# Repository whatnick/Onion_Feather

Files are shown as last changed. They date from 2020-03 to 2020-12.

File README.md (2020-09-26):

View this project on [CADLAB.io](https://cadlab.io/project/23183). 

# Onion-Omega 2 - Feather Adapter
Adapter board adding much needed USB , Lipo , ADC's etc to Onion-Omega form factor and converting it to an Adafruit Feather

## Renders

**Top Render**
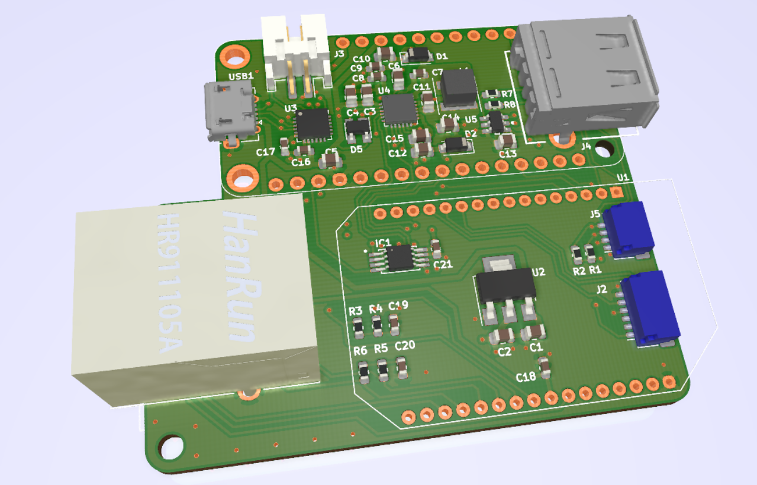
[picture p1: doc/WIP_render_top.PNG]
top render


**Bottom Render**
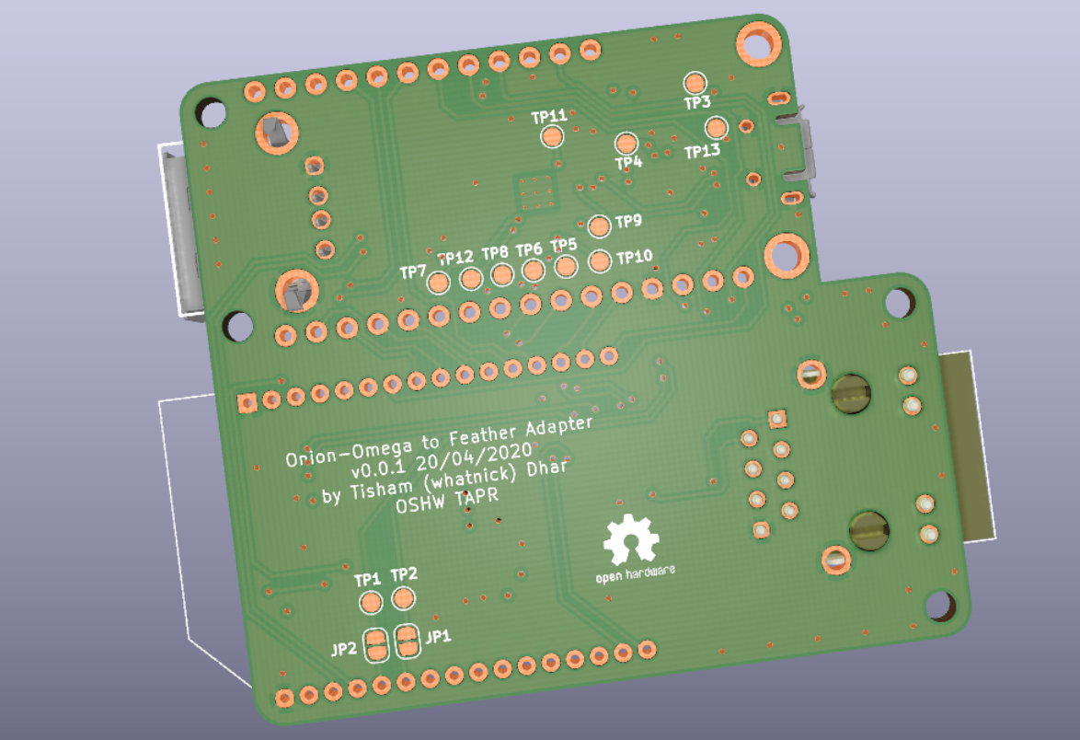
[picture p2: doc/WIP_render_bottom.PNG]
bottom render


## Roadmap Features
- USB-Serial adapter on-board for direct access to Onion Serial port - [CP2102](https://au.mouser.com/ProductDetail/Silicon-Labs/CP2102N-A02-GQFN20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)
- [3.3v](http://www.ti.com/product/TPS63001) and [5v](http://www.ti.com/product/TPS63002) power rails with buck-boost converters and power-path IC's
- USB host to expose the Onion USB pins and add USB devices
- Power OR from VUSB and VBAT using Dual Common Cathode Schottky - [PMEG4010CPA,115](https://au.mouser.com/ProductDetail/Nexperia/PMEG4010CPA115?qs=O%2F7ihdSJpea%252BrtmRoPSGEg%3D%3D)
- Ethernet jack with built-in or external pulse transformer - [Amphenol](https://au.mouser.com/ProductDetail/Amphenol-Commercial-Products/RJMG1BD3B8K1ANR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) or [Hanrun](https://www.snapeda.com/parts/HR911105A/DFRobot/view-part/?ref=search&t=HR911105A)
- Battery charger and buck-boost converter - [BQ25895](http://www.ti.com/product/BQ25895)
- 8-channel I2C ADC for the ADC pins - [AD7997](https://www.analog.com/en/products/ad7997.html#product-overview)
- 2-channel I2C ADC for the ADC pins - [MAX11646EUA+](https://au.mouser.com/new/maxim-integrated/maxim-max11646-max11647/) with other Analog pins services by [Onion PCM/PWM](https://docs.onion.io/omega2-docs/generating-pwm-signals.html) pins.
- Dense 20 pin 1.0 mm pitch board-to-wire connector for all pins - [Molex 203566-2007](https://au.mouser.com/ProductDetail/Molex/203566-2007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)
- Qwiic format JST-SH I2C bus connector - [Qwiic](https://www.sparkfun.com/qwiic)
- USB-host protection using [STF202](https://www.onsemi.com/pub/Collateral/STF202-22T1-D.PDF)
- SPI Bus isolation using [74HC367](https://www.ti.com/lit/ds/symlink/sn74hc367.pdf?ts=1601076323582) hex non-inverting tri-state buffer. This can also be used for I2C bus isolation and driving in later revisions using the left over x2 tristate buffers.

## Reference Prior Art
- [Adafruit ESP32 Huzzah Feather](https://github.com/adafruit/Adafruit-HUZZAH32-ESP32-Feather-PCB)
- [BQ25895 Breakout](https://www.bernebeer.nl/new-bq25895-breakout/)
- [Qwiic Featherwing](https://github.com/hongselectronics/Qwiic_Featherwing)

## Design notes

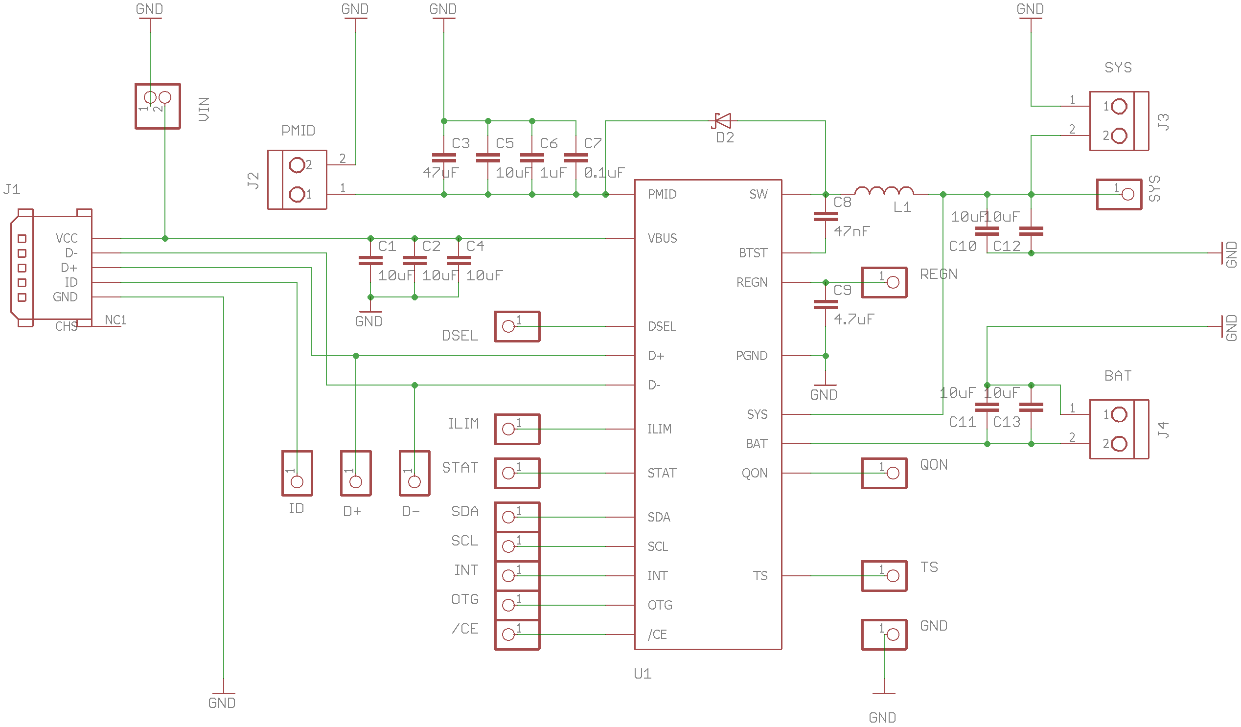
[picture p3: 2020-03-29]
doc/BQ25895-breakout-v2-schematic.png

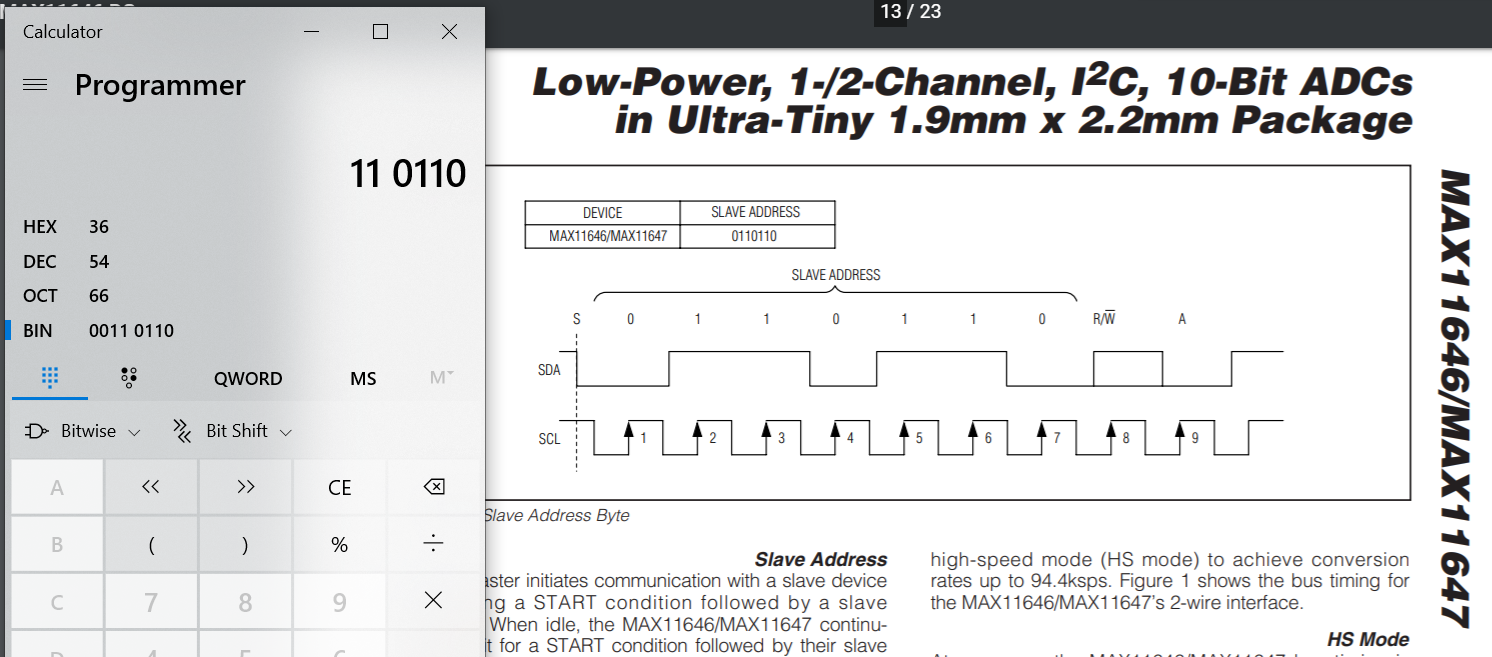
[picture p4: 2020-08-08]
doc/MAX11646_i2c.PNG

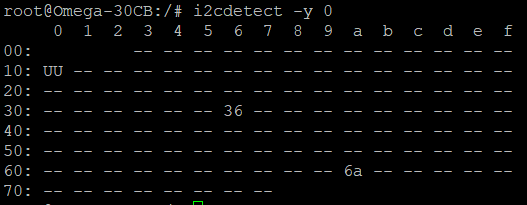
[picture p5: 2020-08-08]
doc/omega_i2c_scan.PNG

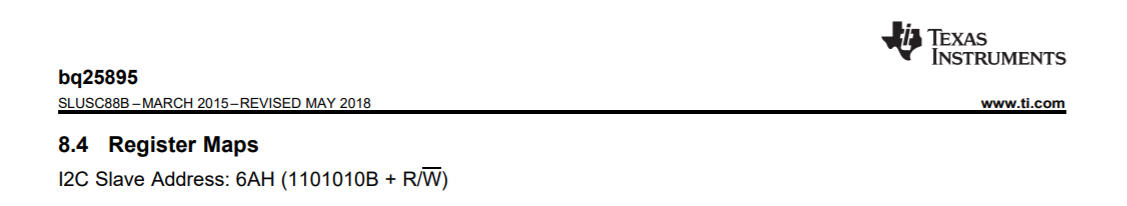
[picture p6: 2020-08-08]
doc/BQ25895_i2c.PNG

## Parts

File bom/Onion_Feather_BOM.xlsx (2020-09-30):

References | manf# | Value | Footprint | Quantity
C6 | 0805YD475MAT2A | 4.7u | C_0805_2012Metric | 1
C8, C17, C19, C20, C21 | C0603C104M4RAC | 100n | C_0603_1608Metric | 5
C9, C16, C18 | C0603C105M4PAC7411 | 1u | C_0603_1608Metric | 3
C7 | C0603C473M4RACTU | 47n | C_0603_1608Metric | 1
C1, C2, C3, C4, C5, C10, C11, C12, C14, C15 | C0805C106K4PAC | 10u | C_0805_2012Metric | 10
C13 | C0805C476M9PACTU | 47u | C_0805_2012Metric | 1
R9, R10, R11 | CRCW060310K0JNEBC | 10K | R_0603_1608Metric | 3
R7, R8 | MCT0603MZ0000ZP500 | 0R | R_0603_1608Metric | 2
R1, R2 | RT0603DRE074K7L | 4.7K | R_0603_1608Metric | 2
R3, R4, R5, R6 | RT0603FRD0749R9L | 49.9R | R_0603_1608Metric | 4
L1 | XAL5030-222MEC | 2.2u | L_Coilcraft_XAL5030 | 1
D1 | MBR130T3G | D_Schottky | D_SOD-123 | 1
D2 | PMEG4010CPA,115 | D_Schottky_x2_KCom_AAK | SOT1061 | 1
D5 | SP0503BAHTG | SP0503BAHT | SOT-143 | 1
U4 | BQ25895RTW | BQ25895RTW | Texas_S-PWQFN-N24_EP2.7x2.7mm_ThermalVias | 1
U3 | CP2102N-A01-GQFN24R | CP2102N-A01-GQFN24 | QFN-24-1EP_4x4mm_P0.5mm_EP2.6x2.6mm | 1
U5 | STF202-22T1G | STF202-22T1G | SOT95P275X110-6N | 1
U2 | TLV1117-33IDCYR | AP1117-33 | SOT-223-3_TabPin2 | 1
USB1 | 47590-0001 | USB_B_Micro | USB_Micro-AB_Molex_47590-0001 | 1
IC1 | MAX11646EUA+T | MAX11646EUA+T | TSSOP-8_4.4x3mm_P0.65mm | 1
IC2 | SN74HC367PWR | SN74HC367PWR | SOP65P640X120-16N | 1
J4 | 67643-0910 | USB_A | 67643-0910 | 1
J1 | HR911105A | HR911105A | HANRUN_HR911105A | 1
J3 | S2B-PH-SM4-TB(LF)(SN) | Conn_01x02 | JST_PH_S2B-PH-SM4-TB_1x02-1MP_P2.00mm_Horizontal | 1
J5 | SM04B-SRSS-TB(LF)(SN) | M04PTH | JST_SH_SM04B-SRSS-TB_1x04-1MP_P1.00mm_Horizontal | 1
J2 | SM06B-SRSS-TB(LF)(SN) | CON_HEADER_PRG_AVR_ICSP-PTH | JST_SH_SM06B-SRSS-TB_1x06-1MP_P1.00mm_Horizontal | 1

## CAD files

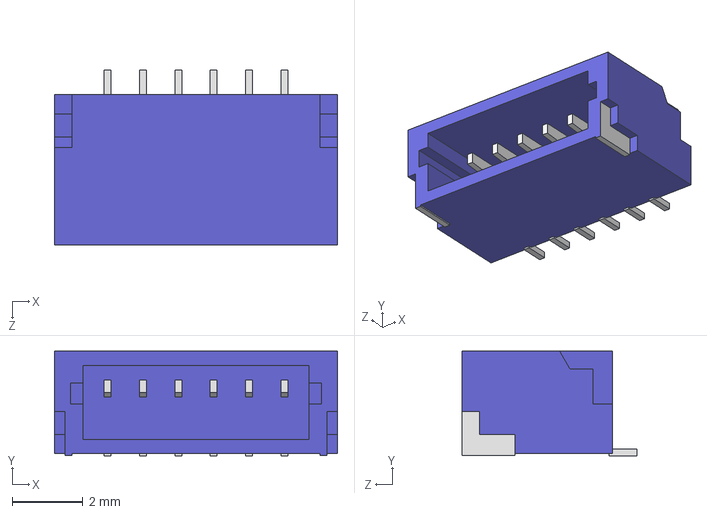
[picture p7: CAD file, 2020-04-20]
3dmodels/SM06B-SRSS-TB.STEP
8.00 x 2.96 x 4.95 mm

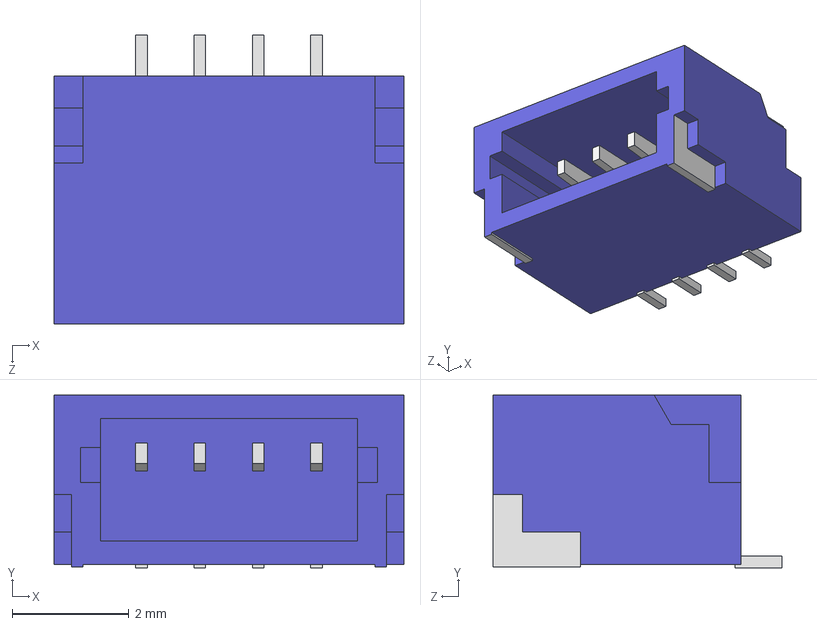
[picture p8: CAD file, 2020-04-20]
3dmodels/SM04B-SRSS-TB.STEP
6.00 x 2.96 x 4.95 mm

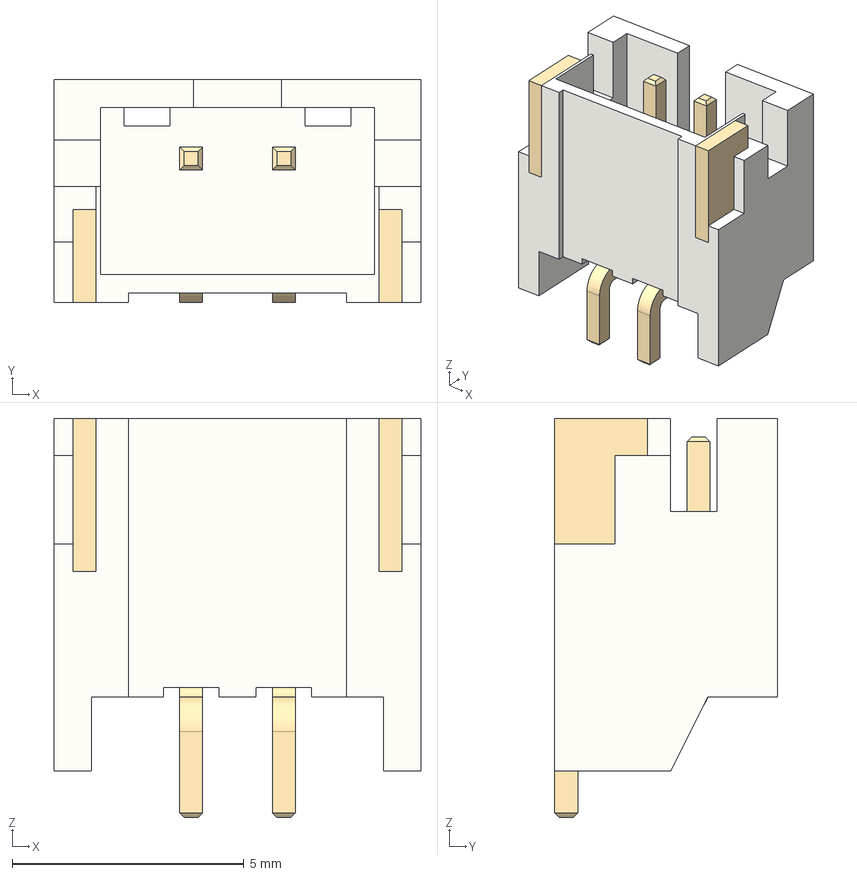
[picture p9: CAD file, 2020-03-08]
3dmodels/S2B-PH-SM4-TB.stp
7.90 x 4.80 x 8.60 mm

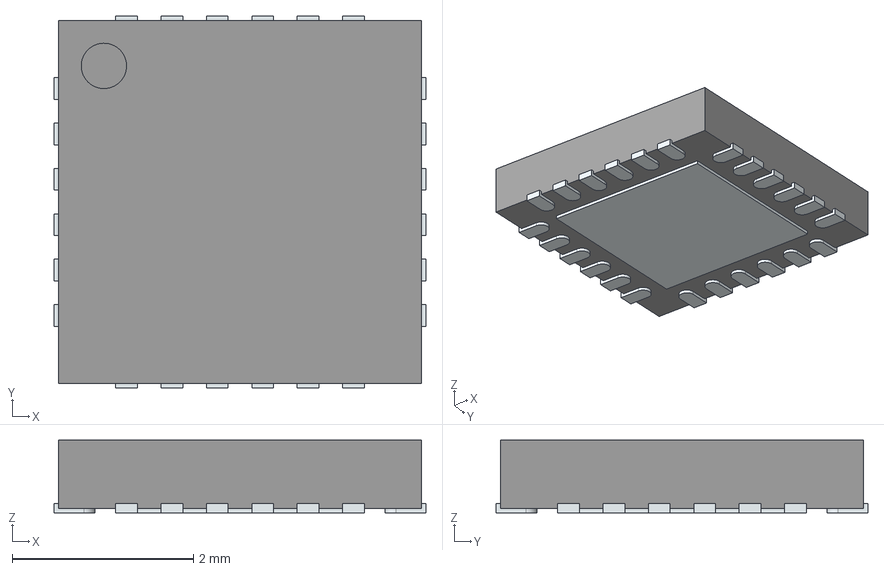
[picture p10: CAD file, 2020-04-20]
3dmodels/BQ25895RTWR.stp
4.10 x 4.10 x 0.8 mm
ThermalPin
PinsArrayLR
PinsArrayTB

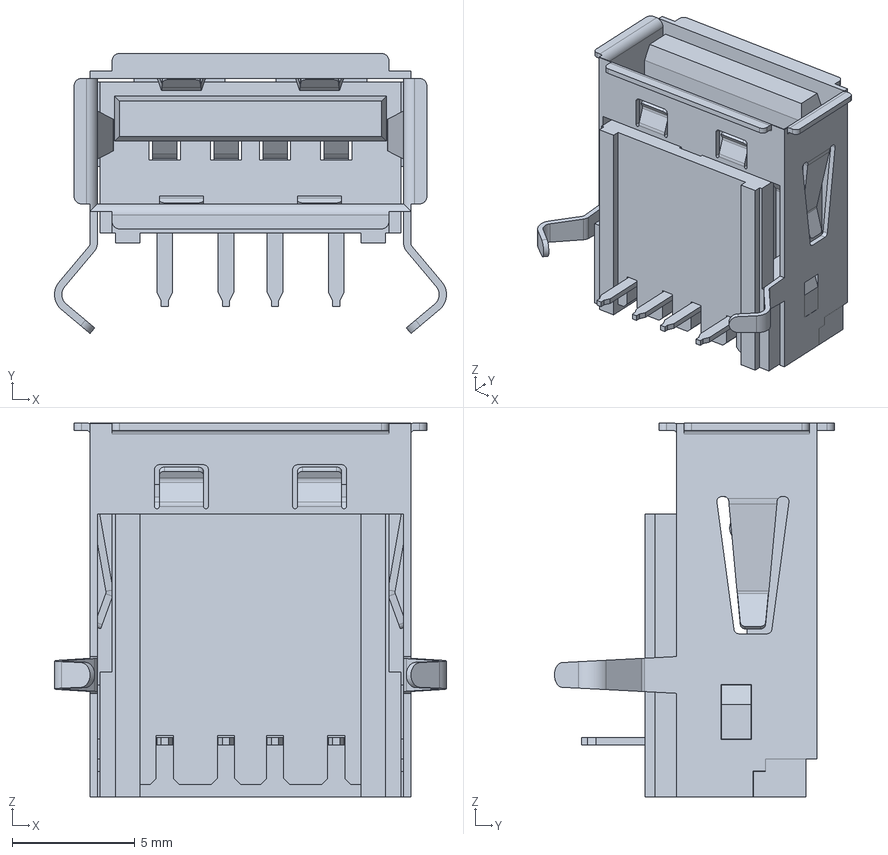
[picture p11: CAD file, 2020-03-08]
3dmodels/67643-0910.stp
16.0 x 11.4 x 15.3 mm

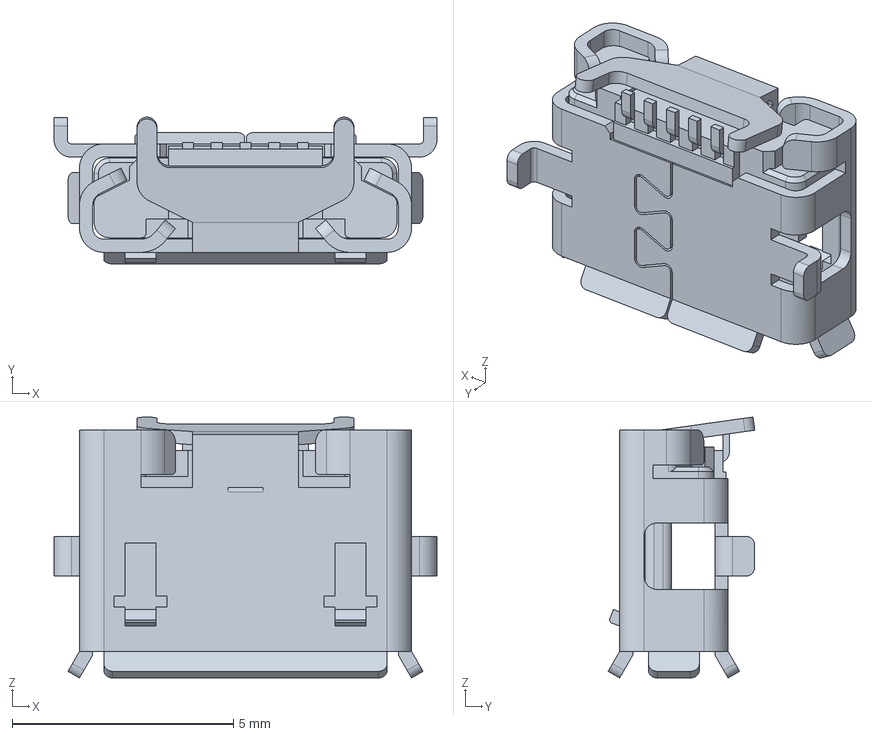
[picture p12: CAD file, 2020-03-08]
3dmodels/47589-0001.stp
8.65 x 3.31 x 5.89 mm

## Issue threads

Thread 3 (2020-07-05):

Battery connector is reversed from Feather Spec

whatnick, 2020-07-05:
The Battery negative positive is reversed in v0.0.1 . This should not cause issues due to built in reverse polarity protection, but better not try. Use a JST-PH 2 terminated cable to reverse batteries for testing other functionalities.

Closed 2020-08-15.

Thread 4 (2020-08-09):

Use CE pin to enable battery charging

whatnick, 2020-08-09:
From the datasheet :
```
Active low Charge Enable pin.
Battery charging is enabled when CHG_CONFIG = 1 and CE pin = Low. CE pin must be pulled High or Low
```

This pin has to be pulled low for battery charging to work. Currently it is disconnected.

Closed 2020-08-15.

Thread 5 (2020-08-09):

Use OTG to enable boost-mode + supply to LDO via boost mode.

whatnick, 2020-08-09:
The OTG mode is not utilized in the battery charger system.
- Tie OTG pin high to enable 5V boosted output while on battery mode.
- Tie LDO input to 5V_BOOST pin to power full system from a charged battery.

```
Boost mode enable pin.
The boost mode is activated when OTG_CONFIG =1, OTG pin is high, and no input source is detected at
VBUS
```

whatnick, 2020-08-15:
Connect a 10k resistor from OTG to PMID and use register settings to enable OTG.

whatnick, 2020-08-16:
Need to increase capacitance on PMID output to supply transition current and prevent power loss during switchover from USB to PMID.

whatnick, 2020-09-19:
OTG tied to VSYS on TI e2e forum advise.

Closed 2020-09-19.

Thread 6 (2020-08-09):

Bias TS pin to prevent charge suspension due to perceived overheat

whatnick, 2020-08-09:
This [schematic checklist](https://e2e.ti.com/cfs-file/__key/communityserver-discussions-components-files/196/BQ25895_5F00_SchematicChecklist-V1p1.pdf) has some very useful tips.

```
1. If thermistor is not used, set TS pin voltage within normal range. 2. If thermistor is used, program
temperature window with a resistor divider from REGN to TS to GND. Charge suspends when TS pin is out of
range.
```

whatnick, 2020-08-11:
This was confirmed to be the issue. Together with tying C&#773;E&#773; low battery charging becomes enabled.

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

Closed 2020-08-15.

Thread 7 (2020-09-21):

Loaded SPI bus causes boot failure

whatnick, 2020-09-21:
The Onion Omega fails to boot if the SPI bus is loaded at startup. Potentially due to bus contention with SPI flash. All SPI bus pins cause this lockup. Investigate using a [tri-state isolator](https://au.mouser.com/ProductDetail/Texas-Instruments/SN74HC367PWT?qs=AgY10sKTvDJcuE1%252BnJ3EhA%3D%3D).

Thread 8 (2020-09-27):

USB Filter is reversed

whatnick, 2020-09-27:
Peripheral and controller connections for STF202 are reversed.

In schematic:
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

In datasheet:
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

whatnick, 2021-01-04:
Tested working

Closed 2021-01-04.

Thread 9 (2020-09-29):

Ethernet PHY connection not detected

whatnick, 2020-09-29:
When ethernet cable is plugged in connection is not detected.

whatnick, 2020-09-30:
Possible fix tying TCT to AVDD.
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

whatnick, 2020-11-24:
Resolved in new revision

Closed 2020-11-24.

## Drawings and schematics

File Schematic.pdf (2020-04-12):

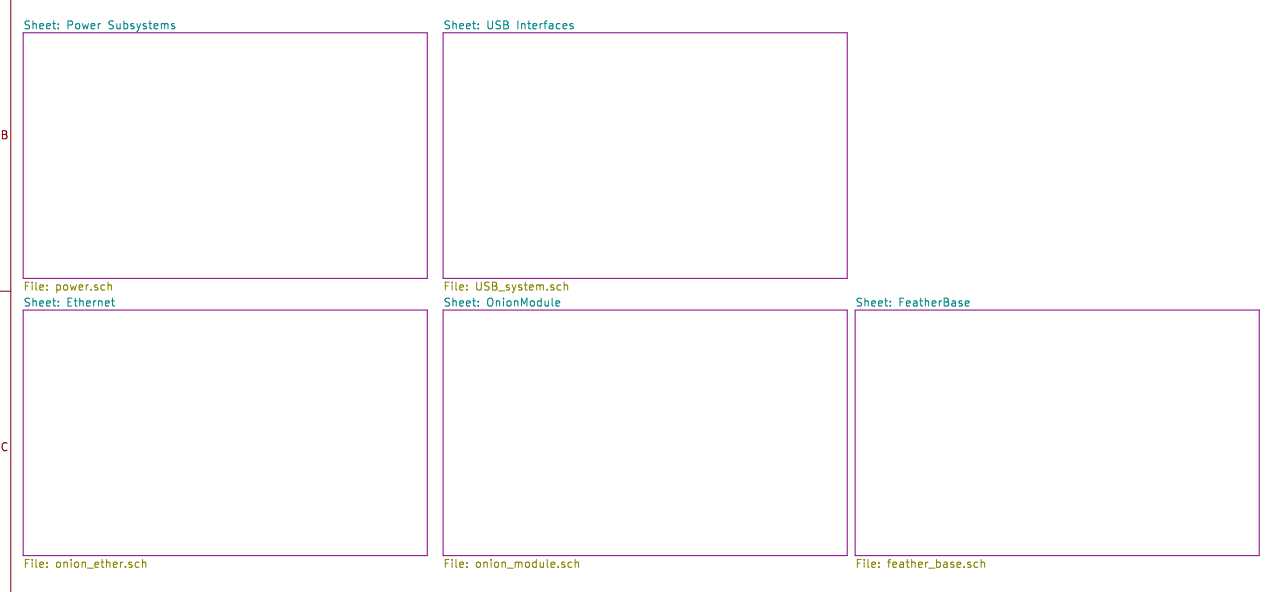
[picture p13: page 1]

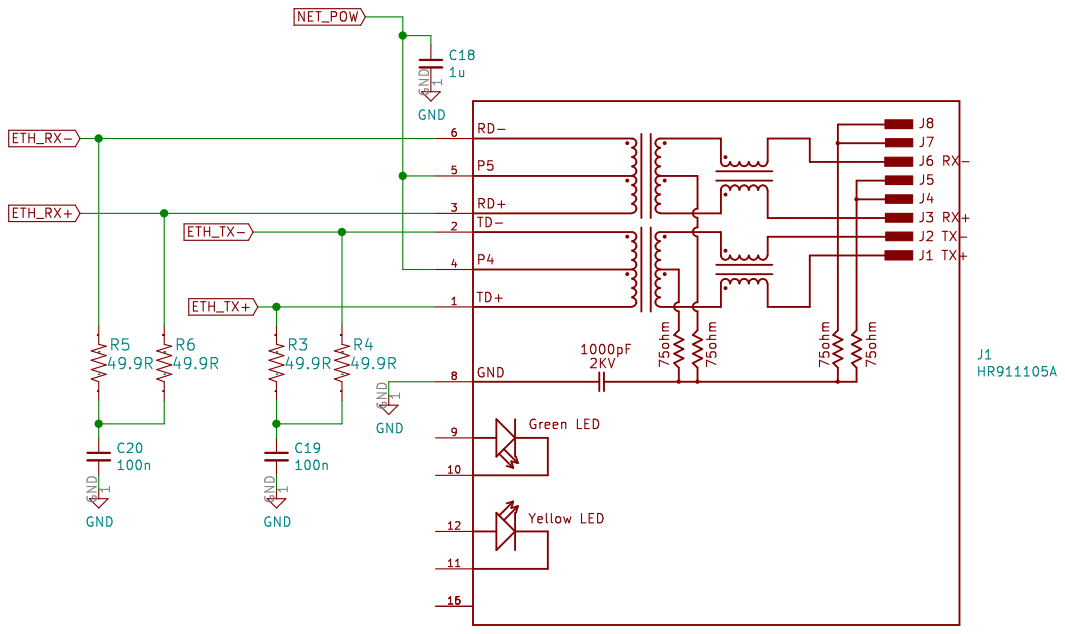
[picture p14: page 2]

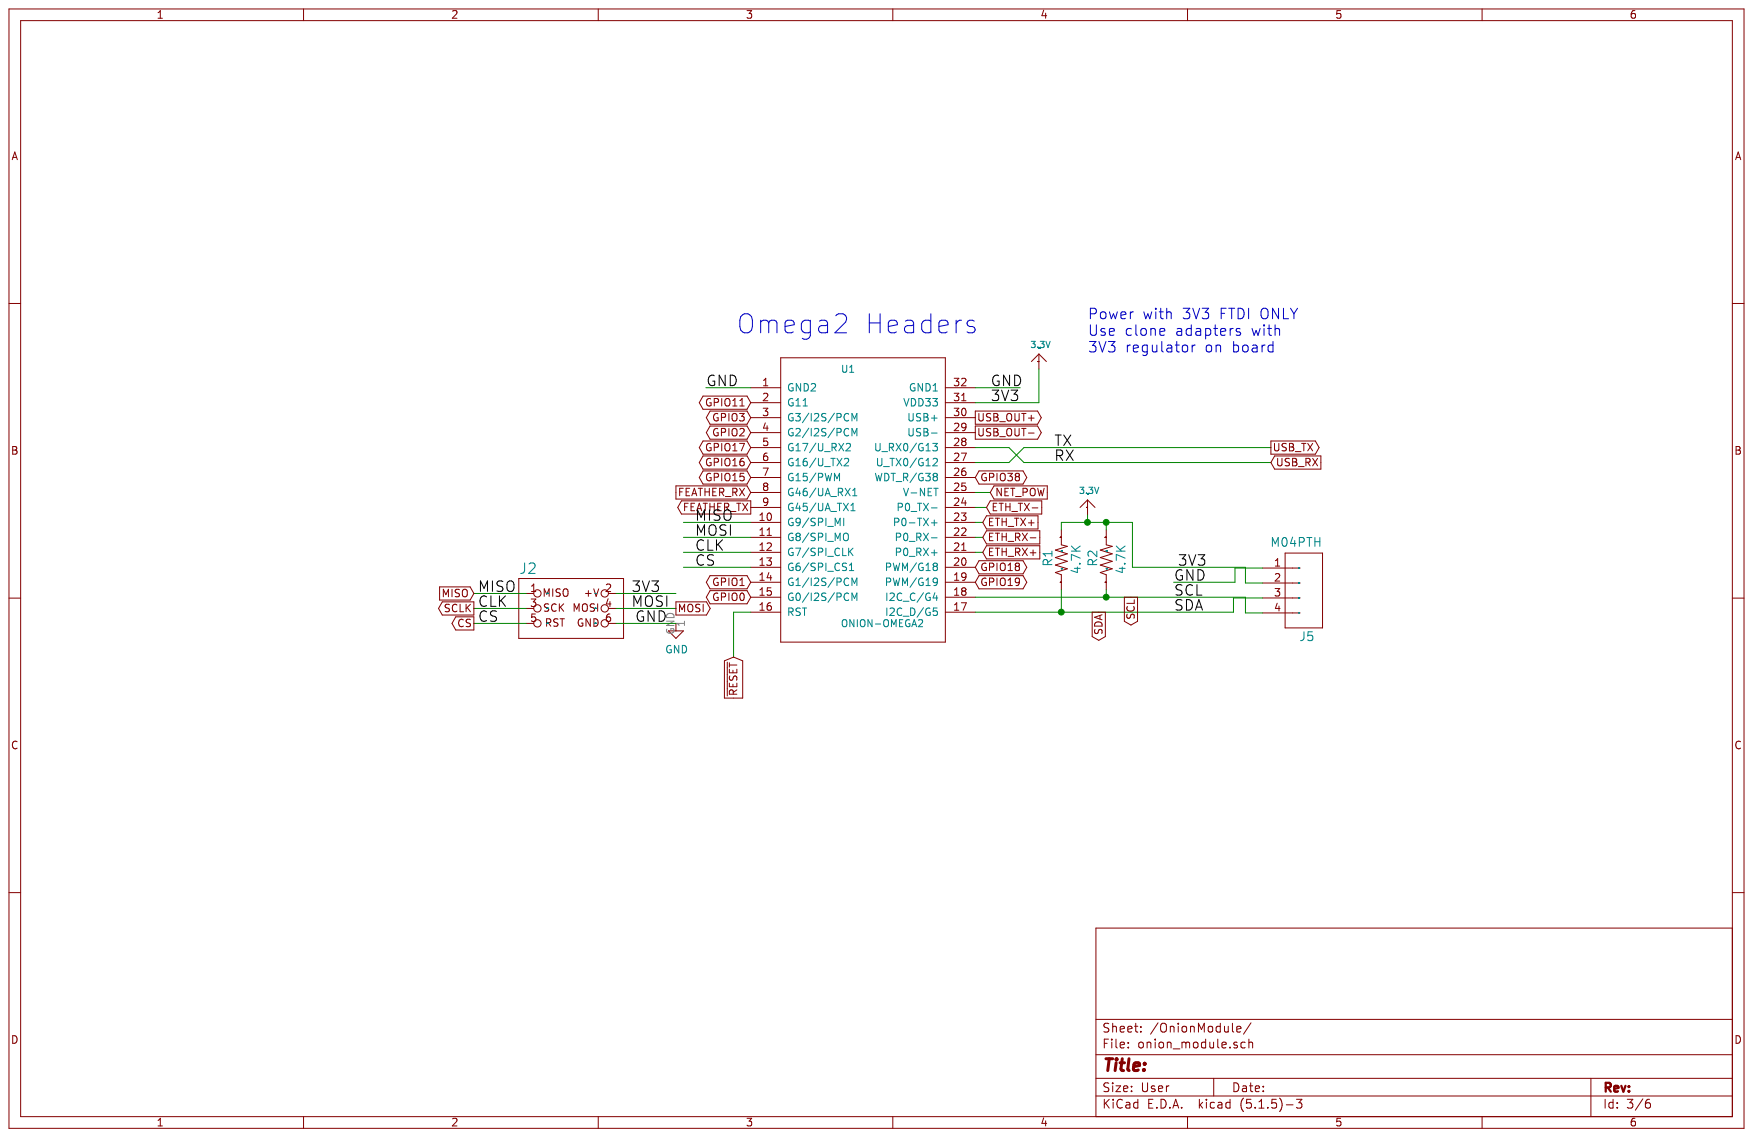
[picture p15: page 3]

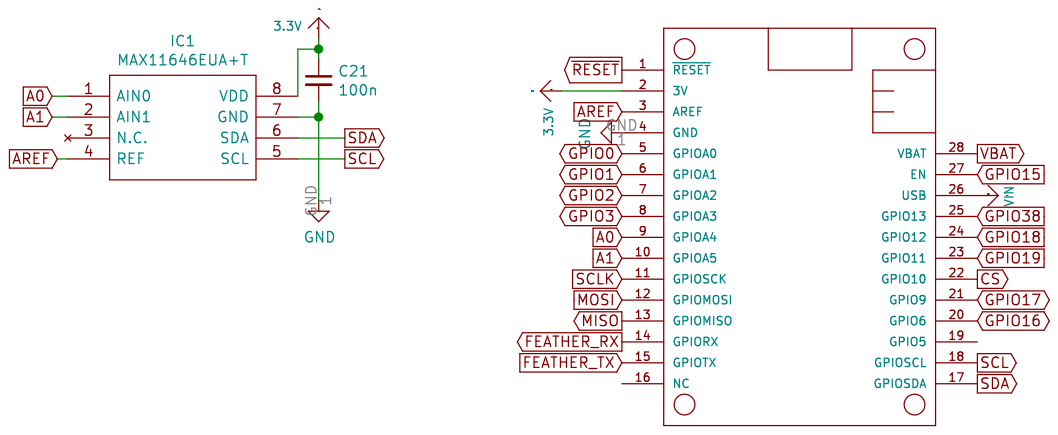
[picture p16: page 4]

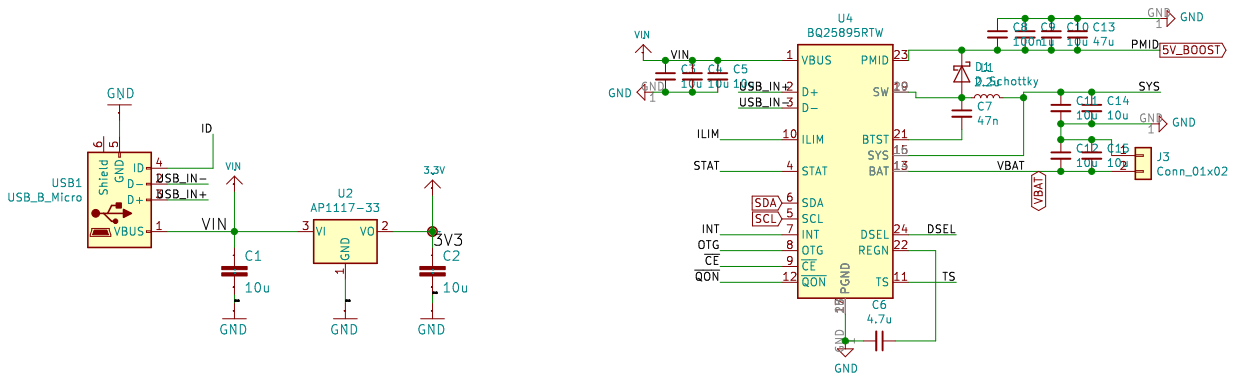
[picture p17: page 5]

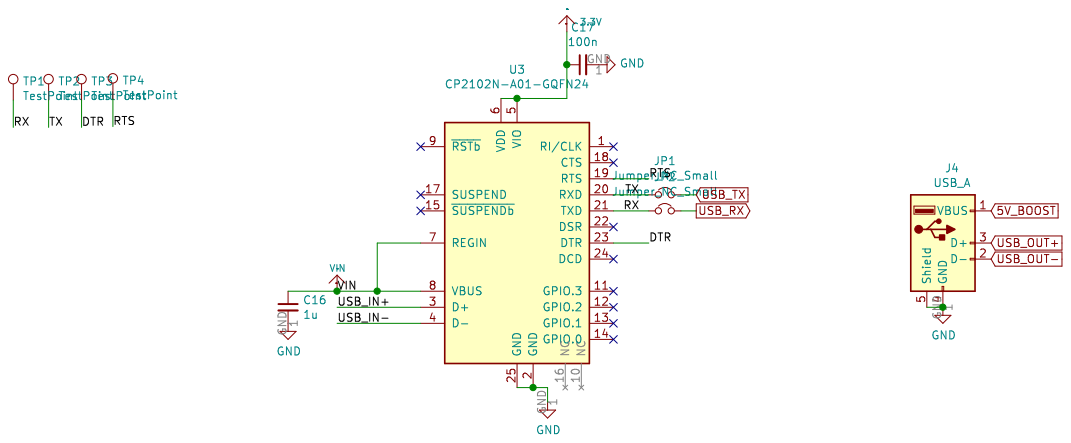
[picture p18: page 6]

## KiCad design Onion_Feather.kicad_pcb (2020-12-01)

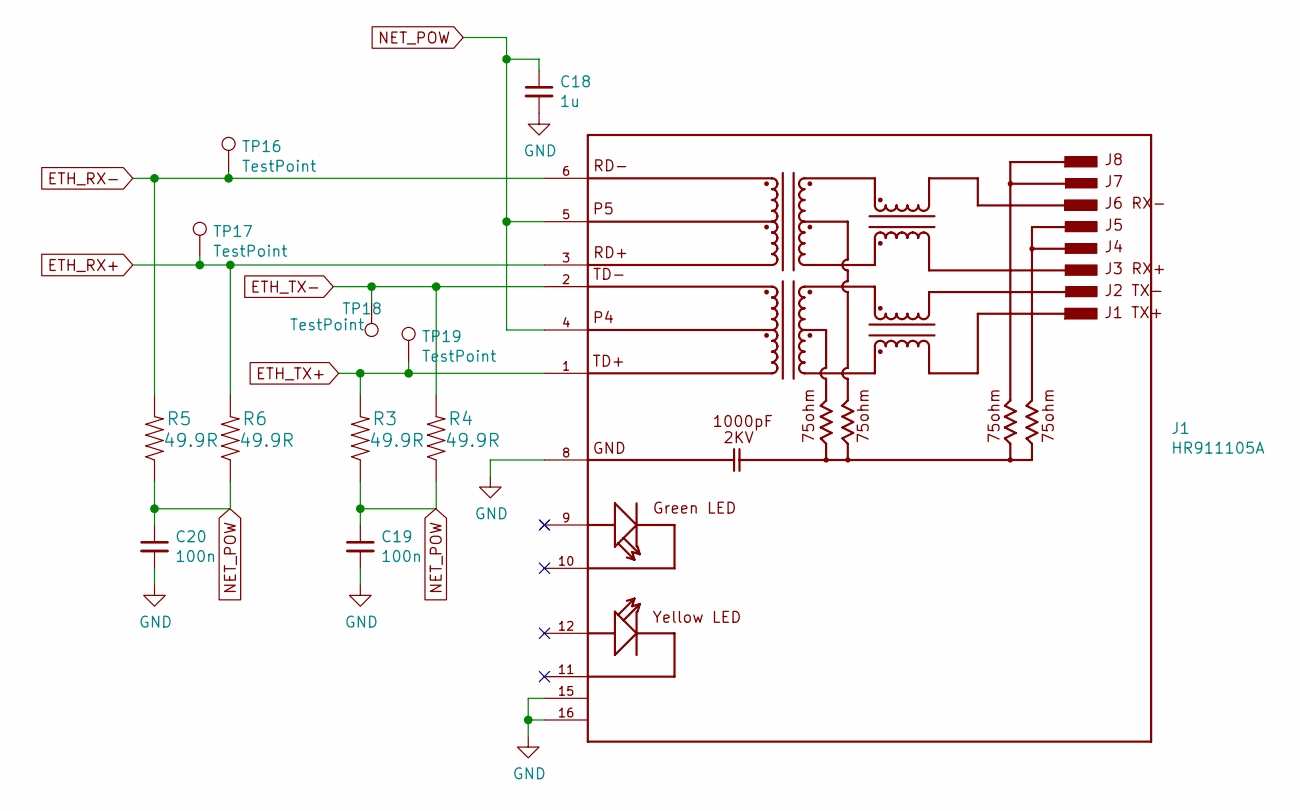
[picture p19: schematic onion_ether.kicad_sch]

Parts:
C18: 1u; C_0603_1608Metric
C19, C20: 100n; C_0603_1608Metric
J1: HR911105A; HANRUN_HR911105A
R3, R4, R5, R6: 49.9R; R_0603_1608Metric
TP16, TP17, TP18, TP19: TestPoint; TestPoint_Pad_D1.5mm

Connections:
ETH_RX+: J1.3 (RD+), R6.2, TP17.1; also elsewhere on the board
ETH_RX-: J1.6 (RD-), R5.2, TP16.1; also elsewhere on the board
ETH_TX+: J1.1 (TD+), R3.2, TP19.1; also elsewhere on the board
ETH_TX-: J1.2 (TD-), R4.2, TP18.1; also elsewhere on the board
GND: C18.2, C19.2, C20.2, J1.8 (GND), J1.15 (SHIELD), J1.16 (SHIELD); also elsewhere on the board
NET_POW: C18.1, C19.1, C20.1, J1.4, J1.5, R3.1, R4.1, R5.1, R6.1; also elsewhere on the board

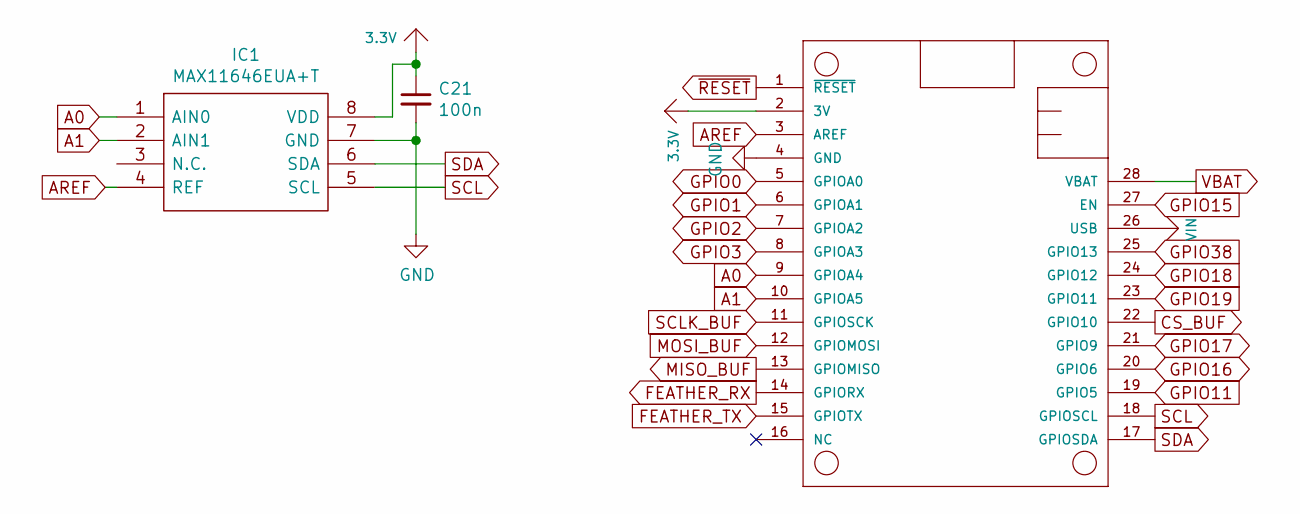
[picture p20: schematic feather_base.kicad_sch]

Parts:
C21: 100n; C_0603_1608Metric
IC1: MAX11646EUA+T; TSSOP-8_4.4x3mm_P0.65mm; Manufacturer_Part_Number MAX11646EUA+T; DigiKey Part Number MAX11646EUA+T-ND
MS1: ADAFRUIT_FEATHERWING; adafruit_featherwing

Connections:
3.3V: C21.1, IC1.8 (VDD), MS1.2 (3V); also elsewhere on the board
A0: IC1.1 (AIN0), MS1.9 (GPIOA4)
A1: IC1.2 (AIN1), MS1.10 (GPIOA5)
AREF: IC1.4 (REF), MS1.3 (AREF)
CS_BUF: MS1.22 (GPIO10); also elsewhere on the board
FEATHER_RX: MS1.14 (GPIORX); also elsewhere on the board
FEATHER_TX: MS1.15 (GPIOTX); also elsewhere on the board
GND: C21.2, IC1.7 (GND), MS1.4 (GND); also elsewhere on the board
GPIO0: MS1.5 (GPIOA0); also elsewhere on the board
GPIO1: MS1.6 (GPIOA1); also elsewhere on the board
GPIO2: MS1.7 (GPIOA2); also elsewhere on the board
GPIO3: MS1.8 (GPIOA3); also elsewhere on the board
GPIO11: MS1.19 (GPIO5); also elsewhere on the board
GPIO15: MS1.27 (EN); also elsewhere on the board
GPIO16: MS1.20 (GPIO6); also elsewhere on the board
GPIO17: MS1.21 (GPIO9); also elsewhere on the board
GPIO18: MS1.24 (GPIO12); also elsewhere on the board
GPIO19: MS1.23 (GPIO11); also elsewhere on the board
GPIO38: MS1.25 (GPIO13); also elsewhere on the board
MISO_BUF: MS1.13 (GPIOMISO); also elsewhere on the board
MOSI_BUF: MS1.12 (GPIOMOSI); also elsewhere on the board
SCL: IC1.5 (SCL), MS1.18 (GPIOSCL); also elsewhere on the board
SCLK_BUF: MS1.11 (GPIOSCK); also elsewhere on the board
SDA: IC1.6 (SDA), MS1.17 (GPIOSDA); also elsewhere on the board
VBAT: MS1.28 (VBAT); also elsewhere on the board
VIN: MS1.26 (USB); also elsewhere on the board
~RESET: MS1.1 (~RESET); also elsewhere on the board

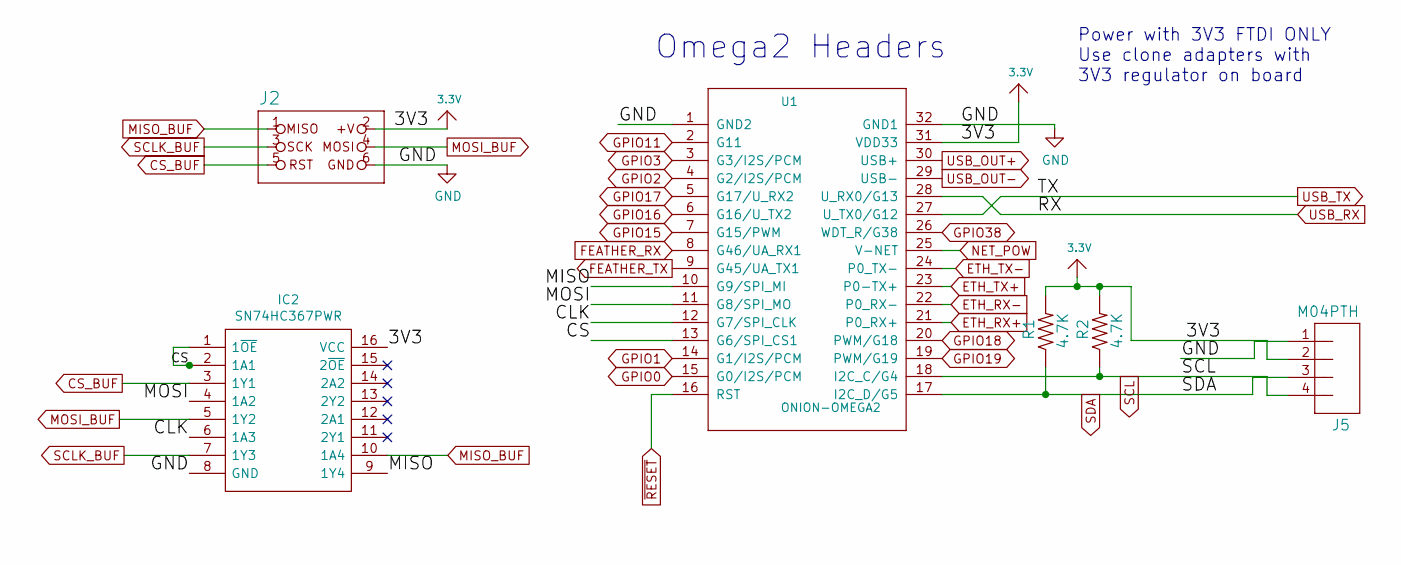
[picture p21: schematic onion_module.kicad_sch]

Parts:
IC2: SN74HC367PWR; SOP65P640X120-16N; Mouser Part Number 595-SN74HC367PWR
J2: CON_HEADER_PRG_AVR_ICSP-PTH; JST_SH_SM06B-SRSS-TB_1x06-1MP_P1.00mm_Horizontal
J5: M04PTH; JST_SH_SM04B-SRSS-TB_1x04-1MP_P1.00mm_Horizontal
R1, R2: 4.7K; R_0603_1608Metric
U1: ONION-OMEGA2; Onion_Omega2+

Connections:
3.3V: IC2.16 (VCC), J2.2 (+V), J5.2, R1.2, R2.2, U1.31 (VDD33); also elsewhere on the board
/OnionModule/CLK: IC2.6 (1A3), U1.12 (G7/SPI_CLK)
/OnionModule/CS: IC2.1 (1~OE), IC2.2 (1A1), U1.13 (G6/SPI_CS1)
/OnionModule/MISO: IC2.9 (1Y4), U1.10 (G9/SPI_MI)
/OnionModule/MOSI: IC2.4 (1A2), U1.11 (G8/SPI_MO)
CS_BUF: IC2.3 (1Y1), J2.5 (RST); also elsewhere on the board
ETH_RX+: U1.21 (P0_RX+); also elsewhere on the board
ETH_RX-: U1.22 (P0_RX-); also elsewhere on the board
ETH_TX+: U1.23 (P0-TX+); also elsewhere on the board
ETH_TX-: U1.24 (P0_TX-); also elsewhere on the board
FEATHER_RX: U1.8 (G46/UA_RX1); also elsewhere on the board
FEATHER_TX: U1.9 (G45/UA_TX1); also elsewhere on the board
GND: IC2.8 (GND), J2.6 (GND), J5.1, U1.1 (GND2), U1.32 (GND1); also elsewhere on the board
GPIO0: U1.15 (G0/I2S/PCM); also elsewhere on the board
GPIO1: U1.14 (G1/I2S/PCM); also elsewhere on the board
GPIO2: U1.4 (G2/I2S/PCM); also elsewhere on the board
GPIO3: U1.3 (G3/I2S/PCM); also elsewhere on the board
GPIO11: U1.2 (G11); also elsewhere on the board
GPIO15: U1.7 (G15/PWM); also elsewhere on the board
GPIO16: U1.6 (G16/U_TX2); also elsewhere on the board
GPIO17: U1.5 (G17/U_RX2); also elsewhere on the board
GPIO18: U1.20 (PWM/G18); also elsewhere on the board
GPIO19: U1.19 (PWM/G19); also elsewhere on the board
GPIO38: U1.26 (WDT_R/G38); also elsewhere on the board
MISO_BUF: IC2.10 (1A4), J2.1 (MISO); also elsewhere on the board
MOSI_BUF: IC2.5 (1Y2), J2.4 (MOSI); also elsewhere on the board
NET_POW: U1.25 (V-NET); also elsewhere on the board
SCL: J5.4, R2.1, U1.18 (I2C_C/G4); also elsewhere on the board
SCLK_BUF: IC2.7 (1Y3), J2.3 (SCK); also elsewhere on the board
SDA: J5.3, R1.1, U1.17 (I2C_D/G5); also elsewhere on the board
USB_OUT+: U1.30 (USB+); also elsewhere on the board
USB_OUT-: U1.29 (USB-); also elsewhere on the board
USB_RX: U1.28 (U_RX0/G13); also elsewhere on the board
USB_TX: U1.27 (U_TX0/G12); also elsewhere on the board
~RESET: U1.16 (RST); also elsewhere on the board

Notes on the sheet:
Omega2 Headers
Power with 3V3 FTDI ONLY Use clone adapters with 3V3 regulator on board

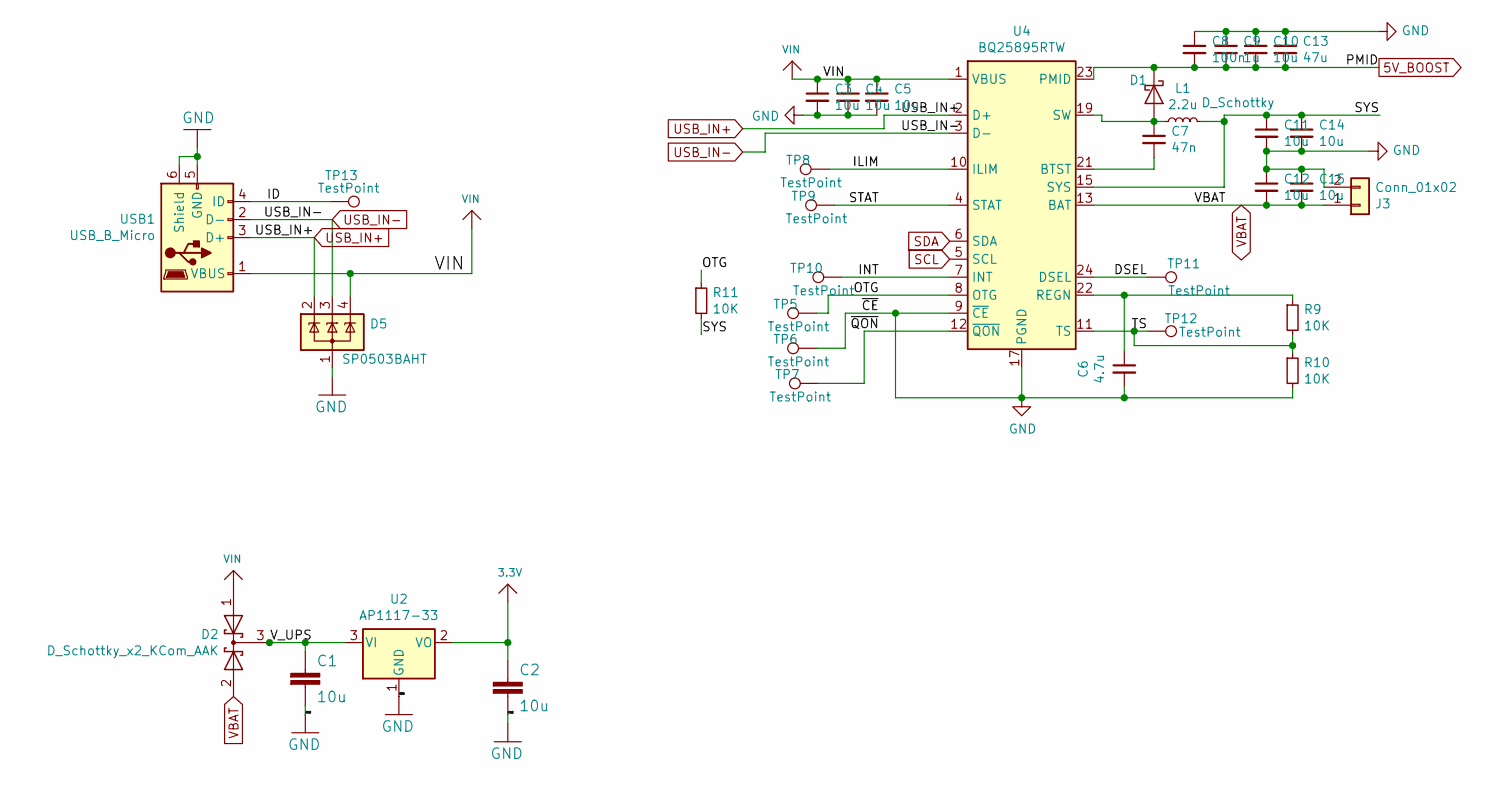
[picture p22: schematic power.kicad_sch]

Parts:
C1, C2, C3, C4, C5, C10, C11, C12, C14, C15: 10u; C_0805_2012Metric
C6: 4.7u; C_0805_2012Metric
C7: 47n; C_0603_1608Metric
C8: 100n; C_0603_1608Metric
C9: 1u; C_0603_1608Metric
C13: 47u; C_0805_2012Metric
D1: D_Schottky; D_SOD-123
D2: D_Schottky_x2_KCom_AAK; SOT1061
D5: SP0503BAHT; SOT-143
J3: Conn_01x02; JST_PH_S2B-PH-SM4-TB_1x02-1MP_P2.00mm_Horizontal
L1: 2.2u; L_Coilcraft_XAL5030
R9, R10, R11: 10K; R_0603_1608Metric
TP5, TP6, TP7, TP8, TP9, TP10, TP11, TP12, TP13: TestPoint; TestPoint_Pad_D1.5mm
U2: AP1117-33; SOT-223-3_TabPin2
U4: BQ25895RTW; Texas_S-PWQFN-N24_EP2.7x2.7mm_ThermalVias
USB1: USB_B_Micro; USB_Micro-AB_Molex_47590-0001

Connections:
3.3V: C2.1, U2.2 (VO); also elsewhere on the board
5V_BOOST: C8.2, C9.2, C10.2, C13.2, D1.1 (K), U4.23 (PMID); also elsewhere on the board
/Power Subsystems/DSEL: TP11.1, U4.24 (DSEL)
/Power Subsystems/ID: TP13.1, USB1.4 (ID)
/Power Subsystems/ILIM: TP8.1, U4.10 (ILIM)
/Power Subsystems/INT: TP10.1, U4.7 (INT)
/Power Subsystems/OTG: R11.1, TP5.1, U4.8 (OTG)
/Power Subsystems/STAT: TP9.1, U4.4 (STAT)
/Power Subsystems/SYS: C11.1, C14.1, L1.2, R11.2, U4.15 (SYS), U4.16 (SYS)
/Power Subsystems/TS: R9.2, R10.1, TP12.1, U4.11 (TS)
/Power Subsystems/V_UPS: C1.1, D2.3 (K), U2.3 (VI)
/Power Subsystems/~CE: TP6.1, U4.9 (~CE)
/Power Subsystems/~QON: TP7.1, U4.12 (~QON)
GND: C1.2, C2.2, C3.2, C4.2, C5.2, C6.2, C8.1, C9.1, C10.1, C11.2, C12.1, C13.1, C14.2, C15.1, D5.1 (A), J3.2, R10.2, U2.1 (GND), U4.17 (PGND), U4.18 (PGND), U4.25 (PGND), USB1.5 (GND), USB1.6 (Shield); also elsewhere on the board
unnamed: C6.1, R9.1, U4.22 (REGN)
unnamed: C7.1, D1.2 (A), L1.1, U4.19 (SW), U4.20 (SW)
unnamed: C7.2, U4.21 (BTST)
SCL: U4.5 (SCL); also elsewhere on the board
SDA: U4.6 (SDA); also elsewhere on the board
USB_IN+: D5.2 (K), U4.2 (D+), USB1.3 (D+); also elsewhere on the board
USB_IN-: D5.3 (K), U4.3 (D-), USB1.2 (D-); also elsewhere on the board
VBAT: C12.2, C15.2, D2.2 (A), J3.1, U4.13 (BAT), U4.14 (BAT); also elsewhere on the board
VIN: C3.1, C4.1, C5.1, D2.1 (A), D5.4 (K), U4.1 (VBUS), USB1.1 (VBUS); also elsewhere on the board

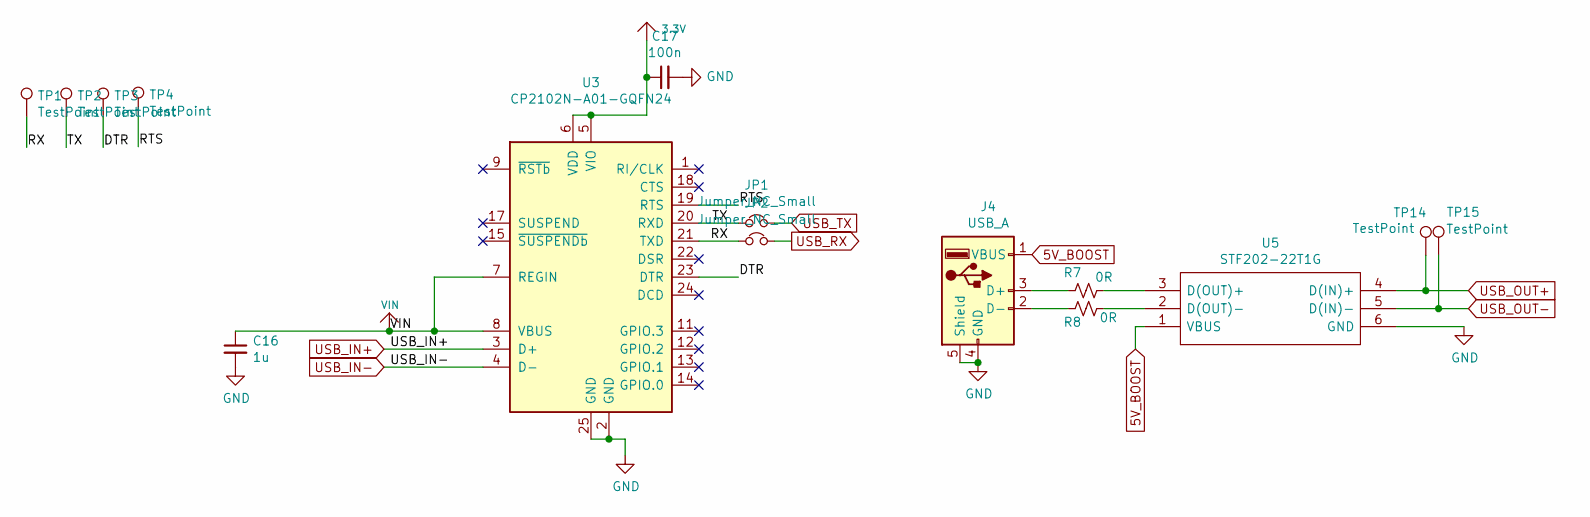
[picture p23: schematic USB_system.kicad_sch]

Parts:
C16: 1u; C_0603_1608Metric
C17: 100n; C_0603_1608Metric
J4: USB_A; 67643-0910
JP1, JP2: Jumper_NC_Small; SolderJumper-2_P1.3mm_Bridged_RoundedPad1.0x1.5mm
R7, R8: 0R; R_0603_1608Metric
TP1, TP2, TP3, TP4, TP14, TP15: TestPoint; TestPoint_Pad_D1.5mm
U3: CP2102N-A01-GQFN24; QFN-24-1EP_4x4mm_P0.5mm_EP2.6x2.6mm
U5: STF202-22T1G; SOT95P275X110-6N; Manufacturer_Part_Number STF202-22T1G; Mouser Part Number 863-STF202-22T1G

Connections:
3.3V: C17.1, U3.5 (VIO), U3.6 (VDD); also elsewhere on the board
5V_BOOST: J4.1 (VBUS), U5.1 (VBUS); also elsewhere on the board
/USB Interfaces/DTR: TP3.1, U3.23 (DTR)
/USB Interfaces/RTS: TP4.1, U3.19 (RTS)
/USB Interfaces/RX: JP2.1, TP1.1, U3.21 (TXD)
/USB Interfaces/TX: JP1.1, TP2.1, U3.20 (RXD)
GND: C16.2, C17.2, J4.4 (GND), J4.5 (Shield), U3.2 (GND), U3.25 (GND), U5.6 (GND); also elsewhere on the board
unnamed: J4.2 (D-), R8.2
unnamed: J4.3 (D+), R7.2
unnamed: R7.1, U5.3 (D(OUT)+)
unnamed: R8.1, U5.2 (D(OUT)-)
USB_IN+: U3.3 (D+); also elsewhere on the board
USB_IN-: U3.4 (D-); also elsewhere on the board
USB_OUT+: TP14.1, U5.4 (D(IN)+); also elsewhere on the board
USB_OUT-: TP15.1, U5.5 (D(IN)-); also elsewhere on the board
USB_RX: JP2.2; also elsewhere on the board
USB_TX: JP1.2; also elsewhere on the board
VIN: C16.1, U3.7 (REGIN), U3.8 (VBUS); also elsewhere on the board

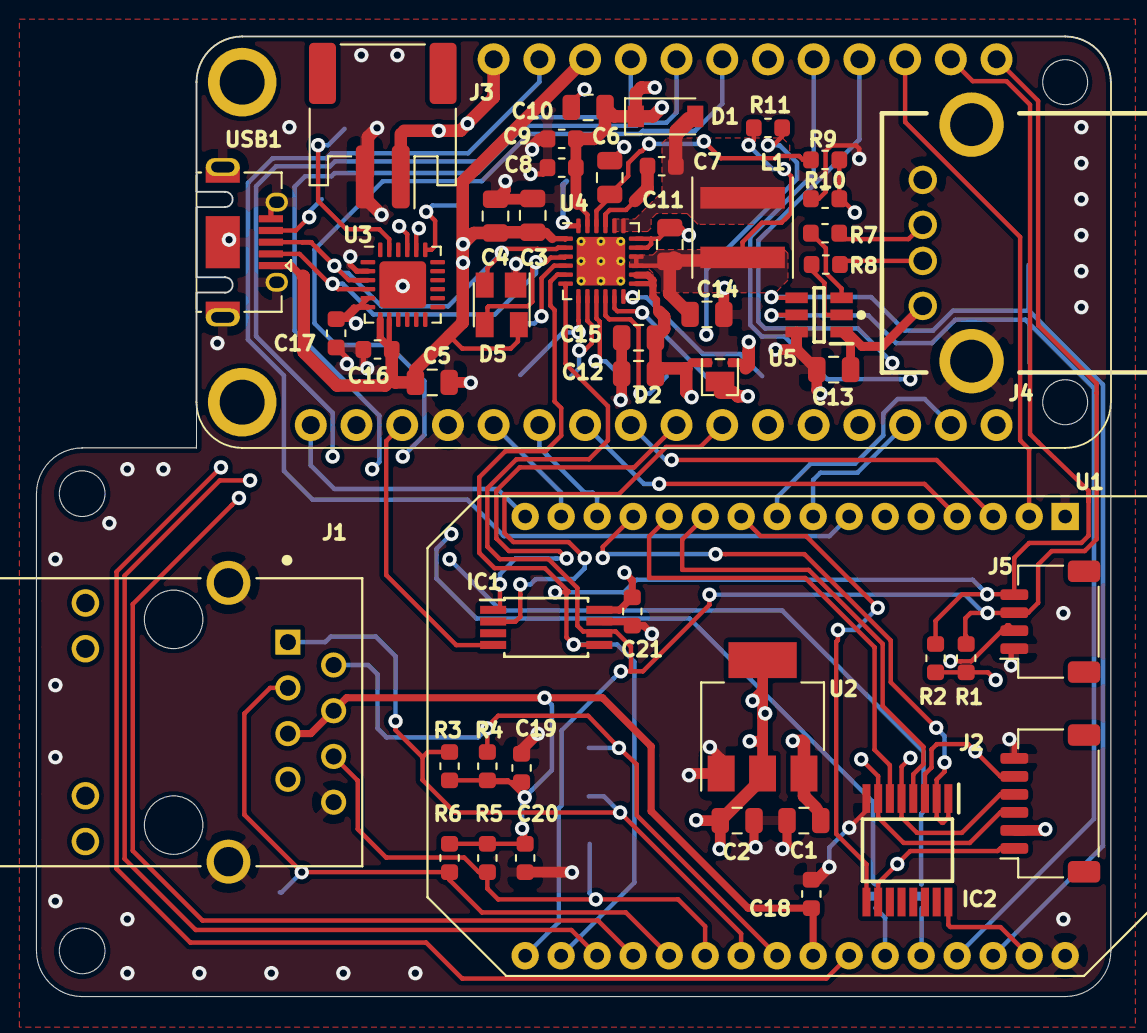
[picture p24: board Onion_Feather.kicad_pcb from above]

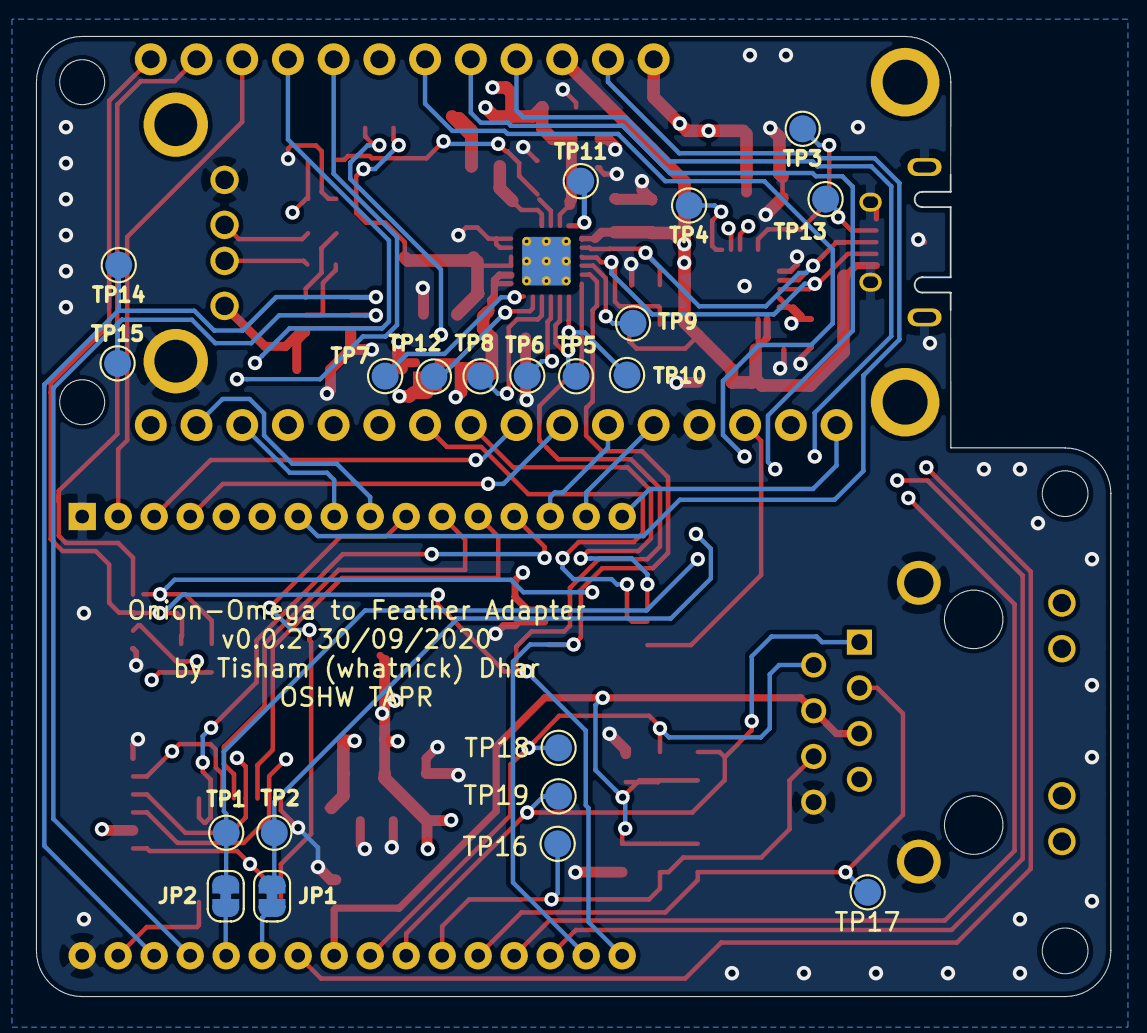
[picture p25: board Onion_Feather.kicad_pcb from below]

Board: 4 copper layers, 59.7 x 53.3 mm, 71 parts (21 on the bottom side), 65 nets.

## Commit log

2020-03-03 Initial import
    [Onion_Feather.kicad_pcb, Onion_Feather.sch]
2020-03-07 Add Hanrun magjack
    [Onion_Feather.kicad_pcb, Onion_Feather.sch, feather_base.sch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]
2020-03-07 Try Hanrun magjack on for size
    [Onion_Feather.kicad_pcb]
2020-03-07 Importing prior art from Eagle
    [Onion_Feather.kicad_pcb, onion_module.sch]
2020-03-08 Added more features and 3D models
    [47589-0001.stp, 67643-0910.stp, Onion_Feather.kicad_pcb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]
2020-03-29 More wiring
    [Onion_Feather.kicad_pcb, USB_system.sch, feather_base.sch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]
2020-03-29 Get fancy with the battery
    [Onion_Feather.kicad_pcb, onion_module.sch, power.sch]
2020-04-04 Work on Power and USB-Serial
    [Onion_Feather.kicad_pcb, USB_system.sch, power.sch]
2020-04-04 Swap pins to use Qwiic spec
    [Onion_Feather.kicad_pcb, onion_module.sch]
2020-04-05 Start making hard choices and wiring GPIO's
    [Onion_Feather.kicad_pcb, USB_system.sch, feather_base.sch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]
2020-04-08 Schematic ready for review
    [Onion_Feather.kicad_pcb, feather_base.sch, onion_ether.sch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]
2020-04-10 USB protection, schematic Update
    [Onion_Feather.kicad_pcb, USB_system.sch, feather_base.sch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]
2020-04-11 Schematic update
    [Onion_Feather.kicad_pcb, USB_system.sch, feather_base.sch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]
2020-04-12 Schematic and library update, 0 errors
    [USB_system.sch, onion_ether.sch, power.sch]
2020-04-17 Routing done
    [Onion_Feather.kicad_pcb, feather_base.sch]
2020-04-19 Silkscrenn fix
    [Onion_Feather.kicad_pcb]
2020-04-19 PCB update, edge vias
    [Onion_Feather.kicad_pcb]
2020-04-20 Add 3d models , silkscreen and renders
    [BQ25895RTWR.stp, Onion_Feather.kicad_pcb, SM04B-SRSS-TB.STEP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]
2020-04-20 Add some part no.
    [USB_system.sch, feather_base.sch, onion_module.sch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]
2020-04-22 Add gerbers and BOM
    [Onion_Feather-B_Cu.gbl, Onion_Feather-B_Mask.gbs, Onion_Feather-B_Paste.gbp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]
2020-04-24 Update BOM
    [Onion_Feather_BOM.xlsx, USB_system.sch, feather_base.sch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]
2020-06-28 Fix up BOM , add positions for assembly
    [Onion_Feather_BOM.xlsx, USB_system.sch, feather_base.sch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]
2020-08-08 Validate i2c devices
2020-08-08 #3 Correct battery connector and align PCB/Schema
    [Onion_Feather.kicad_pcb, feather_base.sch, power.sch]
2020-08-09 Add battery charger driver
2020-08-11 #6 Fix CE and TS pins
    [Onion_Feather.kicad_pcb, power.sch]
2020-08-12 Note proposed power OR schottky
2020-08-12 WIP on diode OR
    [Onion_Feather.kicad_pcb, feather_base.sch, power.sch]
2020-08-13 Enable cycle flag to switch BATFET
2020-08-14 Use common cathode and reroute
    [Onion_Feather.kicad_pcb, power.sch]
2020-09-19 #5 Add OTG bias and clean up courtyard
    [Onion_Feather.kicad_pcb, power.sch]
2020-09-20 Start on sparkfun button
2020-09-20 Support multiple buttons and LED
2020-09-22 #7 Add tri-state buffer
    [Onion_Feather.kicad_pcb, onion_module.sch]
2020-09-26 #7 Wire in tristate buffer
    [feather_base.sch, onion_module.sch]
2020-09-27 #7 Re-route with tristate buffer
    [Onion_Feather.kicad_pcb]
2020-09-27 #8 Fix broken USB filter symbol and rewire
    [USB_system.sch, onion_module.sch]
2020-09-27 #8 Re-route USB filter
    [Onion_Feather.kicad_pcb]
2020-09-29 #9 Add some testpoints for ethernet
    [Onion_Feather.kicad_pcb, onion_ether.sch]
2020-09-30 #9 Tie center pin to NET_POW
    [Onion_Feather.kicad_pcb, onion_ether.sch]
2020-09-30 New manufacture files
    [Onion_Feather-B_Cu.gbl, Onion_Feather-B_Mask.gbs, Onion_Feather-B_Paste.gbp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]
2020-11-17 Add oled sample
2020-12-01 Move to KiCAD nightly
    [Onion_Feather.kicad_pcb, Onion_Feather.kicad_sch, USB_system.kicad_sch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]
